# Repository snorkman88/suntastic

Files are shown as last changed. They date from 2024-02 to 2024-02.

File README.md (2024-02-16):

# DRAFT: Suntastic
An ultra low-power management board for meshtastic solar repeater devices.

## Overview

This repository contains the design proposal of a power management board for ultra low power embedded devices. The board features a solar charger circuit with Maximum Power Point Tracking (MPPT) for 5V solar panels, two DC-DC converters, a load switch control with adjustable hysteresis and an external Watchdog Timer.

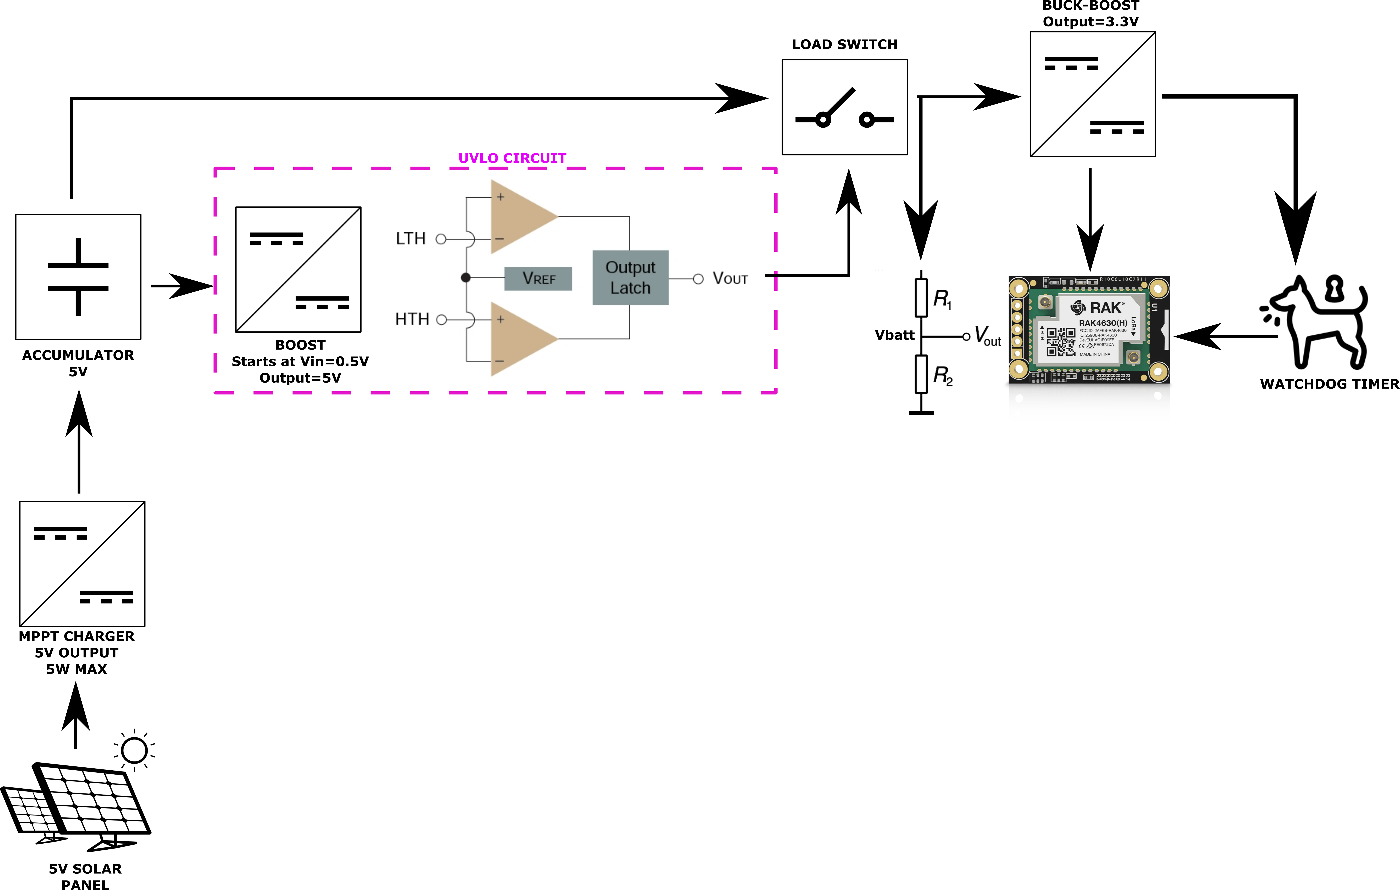
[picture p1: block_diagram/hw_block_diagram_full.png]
Hardware block diagram


## Why did I start this project?

### MPPT is a must
I recently started working with [Meshtastic](https://meshtastic.org/) and decided to deploy solar powered repeaters based on the WisBlock Core module that contains a RAK4631. So far it's been recommended to use this core module with any of the available base boards, however after inspecting [RAK's 19007](https://store.rakwireless.com/products/rak19007-wisblock-base-board-2nd-gen) base board, I noticed that the battery charging stage based on the [TP4054](https://www.laskakit.cz/user/related_files/tp4054.pdf) is not performing any kind of optimization to maximize the power available from the solar input.  

In contrast to linear chargers, MPPT chargers excel in extracting energy from solar panels under conditions such as partial shading, changing light angles, and fluctuating weather conditions. This adaptability is crucial for maximizing energy harvesting in real-world scenarios. By efficiently managing the charging process, MPPT helps prevent overcharging or undercharging of the accumulators in small IoT devices. This contributes to extending the overall lifespan of the battery, reducing the frequency of maintenance or battery replacement, and enhancing the device's reliability.  

### Reduce the current consumption of all the additional electronics
The recommended Wisblock base board RAK19007 contains extra electronics that are not really necessary once the RAK4631 core module has been correctly configured and flashed. This extra electronics however, do imply extra power consumption.  

As it's been empirically proven in [this thread](https://meshtastic.discourse.group/t/running-rak4631-without-the-rak19007/7021/21) once the RAK4631 core is flashed, it only needs a proper 3.3V power source to start working.  
However RAK actually recommends providing two voltage sources to the RAK4631, one that supplies power to the input of internal DC-DC buck converter and another 3.3V for the SX1262 chip. [SEE THIS POST](https://forum.rakwireless.com/t/rak4631-without-baseboard/10177/18)

### Supercapacitors as main energy storage
Another point that motivated the start of this project is the use of supercapacitors instead of conventional LiPo or LiFePo batteries. Whether supercapacitors are better than batteries for IoT devices depends on the specific requirements of the application. Here are some factors to consider:

1. Power Density:
Supercapacitors generally have higher power density than batteries. They can quickly charge and discharge, making them suitable for applications that require rapid bursts of energy. This can be advantageous in IoT devices that need to transmit data or perform periodic tasks quickly.

2. Cycle Life:
Supercapacitors often have a longer cycle life compared to batteries. Compared to batteries, they can withstand a large number of charge-discharge cycles without significant degradation in their structure even when being completely depleted and its output voltage drops down to 0V. This is beneficial for IoT devices that may need to operate for extended periods without maintenance.

3. Lifetime and Maintenance:
Supercapacitors can have a longer overall lifetime than batteries, as they do not suffer from the same degradation issues over time. They also require less maintenance since they do not have the same chemical processes that can lead to wear and tear in batteries.

4. Size and Weight:
Supercapacitors can be more compact and lighter than batteries, which is important for IoT devices with size and weight constraints. This is particularly relevant for small, portable devices or those with limited space.

5. Temperature Sensitivity:
Supercapacitors are known for their resilience to temperature variations, making them suitable for applications in harsh environments. This can be an advantage in IoT devices deployed in diverse environments where temperature fluctuations are common. Supercapacitors have a temperature range of operation og -40°C to 85°C or even higher in some cases.

6. Energy Density:
Batteries typically have higher energy density, meaning they can store more energy per unit of volume or weight. If the IoT device requires long periods of operation without recharging, a battery might be a more suitable choice.

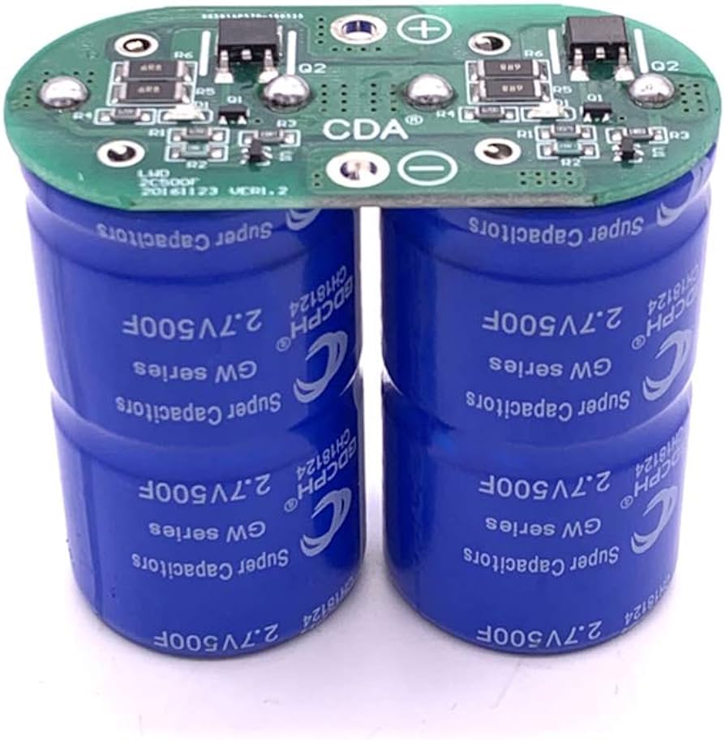
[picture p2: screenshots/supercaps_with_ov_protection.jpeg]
supercaps
  

In summary, the choice between supercapacitors and batteries for powering IoT devices depends on the specific requirements of the application. Supercapacitors may be a better choice for applications that require high power density, quick charge/discharge cycles, and long cycle life, while batteries may be preferable when higher energy density and longer operating periods without recharging are crucial. Each technology has its own strengths and limitations, and the decision should be based on the specific needs and constraints of the IoT deployment.  

### External Watchdog timers are sometimes needed
For IoT devices deployed in remote areas, the incorporation of an external watchdog timer becomes even more critical due to the challenges associated with limited accessibility and maintenance. Remote locations often entail harsh environmental conditions and restricted physical access, making it challenging to address issues promptly. The watchdog timer becomes a crucial asset in such scenarios as it autonomously monitors the device's operational state and intervenes in the case of failures. This capability ensures that even if a device experiences a software glitch or hardware malfunction, it can autonomously reset itself, mitigating potential downtime without requiring manual intervention.  

The reliability and self-correcting nature of an external watchdog timer contribute significantly to the overall resilience of IoT devices in remote deployments, enhancing their ability to function autonomously and maintain consistent operation in challenging and hard-to-reach environments.

## IMPORTANT
IMPORTANT: this board has been specifically thought to handle 5V solar panels and supercapacitors up to a voltage of 5.4V max.

## Table of Contents

- [Solar Charger Circuit](#solar-charger-circuit)
- [DC-DC Converters](#dc-dc-converters)
  - [Boost Converter](#boost-converter)
  - [Buck-Boost Converter](#buck-boost-converter)
- [UVLO - Schmitt Trigger Control](#schmitt-trigger-control)
- [External Watchdog timer](#watchdog-timer)
- [Monitoring of the voltage seen on the accumulator]()

## Solar Charger Circuit

The solar charger circuit is designed to efficiently charge an accumulator using 5V solar panels. It incorporates Maximum Power Point Tracking (MPPT) to optimize the energy harvesting from the solar panels.  

The [SPV1040](https://www.st.com/en/power-management/spv1040.html) device is a low power, low voltage, monolithic step-up converter with an input voltage range from 0.3 V to 5.5 V, capable of maximizing the energy generated by solar cells (or fuel cells), where low input voltage handling capability is extremely important. Thanks to the embedded MPPT algorithm, even under varying environmental conditions (such as irradiation, dirt, temperature) the SPV1040 offers maximum efficiency in terms of power harvested from the cells and transferred to the output. The device employs a voltage regulation loop, which fixes the charging battery voltage via a resistor divider.  



It is possible to set the maximum output current according to charging requirements by a sense resistor .

## DC-DC Converters

### Boost Converter

The first DC-DC converter that is presented is a boost converter responsible for powering the control stage and the input of the internal DC/DC converter present in the nRF52840.  
It is based on a [TPS61202](https://www.sparkfun.com/datasheets/Prototyping/tps61200.pdf) from Texas Instruments and takes variable voltage seen at the accumulator (i.e a supercapacitor) and converts it to a 5V one.  
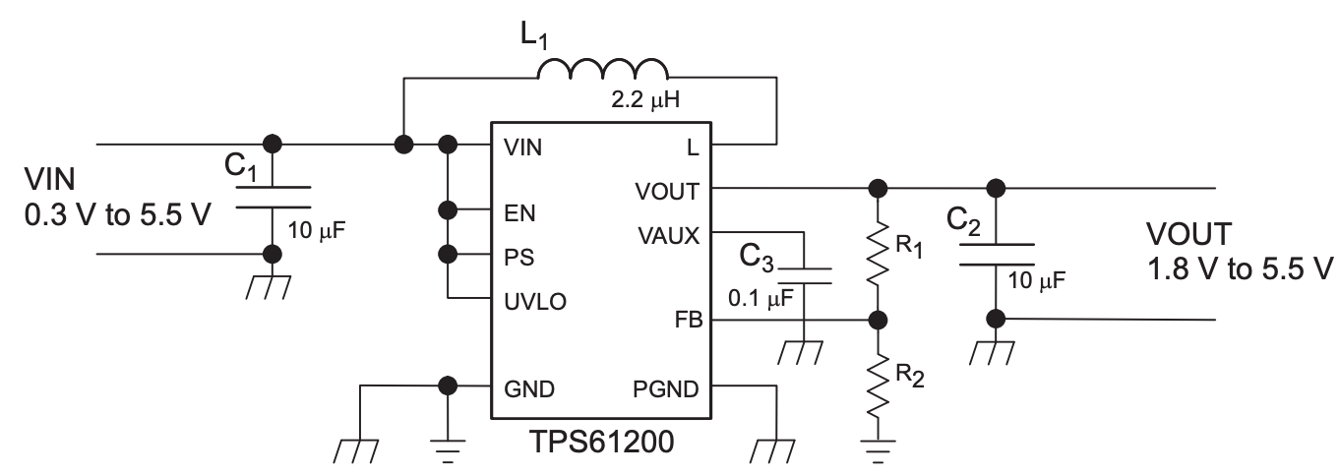
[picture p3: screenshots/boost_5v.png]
boost_5v
  
This boost converter features a very low start-up voltage (0.5V) and Iq=50uA when in operation.  
For the very first version of this board, in order to save schematic and PCB design time, it would be ideal to use a ready-to-use board like the Pololu [U1V10F5](https://thepihut.com/products/pololu-5v-step-up-voltage-regulator-u1v10f5).  

For more info about this module visit [Pololu Site](https://www.pololu.com/product/2564)

### Buck-Boost Converter or LDO for obtaining 3.3V

The second voltage regulator is in charge of supplying power to the 3.3 V bus to which the SX1262 chip (present in the WisBlock RAK4631) and watchdog timer are connected.  
This regulator should only start operating after the load switch controlled by the UVLO is closed.  
It is very important to remark that clean power supplies are essential for RF transceivers to maintain optimal performance. RF signals are sensitive to electrical noise, and any disruptions in the power supply can lead to signal degradation.  

In the case a buck-boost converter (like the TPS63020) is adopted, then it could either take as an input the variable voltage from the supercapacitor or the 5V constant output coming out of the TPS61202. This approach however, necessitates more filtering of the output voltage.  

Using LDOs on the other hand, requires an input votlage higher than the one desired at the output (in this case 3.3V). Ergo, connecting its input directly to the supercapacitor is not an acceptable approach.  
Although taking 5V coming from the TPS61202 as input voltage might bring some input ripple, the PSRR of an LDO contributes to suppress it at the output.  
In the case the output of the LDO still shows some ringing at high frequencies (usually as peaks on the waveform), ferrite beads should be placed to filter the desired frequencies.  

For more detailed info about this visit this [Application Note from Analog Device - AN101](https://www.analog.com/media/en/technical-documentation/application-notes/an101f.pdf)  

or watch this video  

[![Video]()](https://www.youtube.com/watch?v=WxhjLIu-vPg&ab_channel=LinearTechnology)

### Why are there two DC-DC converters?
It is desirable that the UVLO control circuit starts operating as early as possible if there is enough input power (around Vin=0.7V) and BEFORE any other electronic device. The opposite behaviour is also desired. In other words, when the input voltage coming from the accumulator decreases, the UVLO should be last part that is turned off.

Since it's expected that the control stage consumes only a few microamps when operating, the output voltage of 5V should remain steady while the accumulator (i.e: supercapacitor) continues to charge. Once the voltage seen accross the terminals of the accumulator reaches the lock-in voltage, the second converter, external watchdog timer and microcontroller will be energised.

## UVLO - Schmitt Trigger Control

The project includes an UVLO circuit with with adjustable hysteresis that enables or disables a load switch. The load connected to the switch will be the main [Buck-Boost Converter](#buck-boost-converter) that feeds power the RAK431 or another microcontroller.  

Since the supercapacitor bank I have at the moment (250F x 5.4V) already comes with an extra PCB to protect them against overvoltages higher than 5V, and for [this simulation only](https://www.falstad.com/circuit/circuitjs.html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), a value of 3V was chosen for the upper limit and 1V for the lower one.  

Since it's the intention to make the supercapacitor charge up to a voltage value close to the maximum, the final version will have a lock-in voltage closer to 5V or 5.4V if I get a bank without the overvoltage protection. The lower limit of the hysterisis window will be kept at 1V.  
In order to avoid flickering of the output when the supercap voltage reaches the lock-in and -out values, an SR latch based on NOR gates will either SET (and keep it HIGH even if the input flickers) when the lock-in voltage is reached; and RESET its output when reaching the lock-out value.  

The circuit consists of two [TLV3691](https://www.ti.com/lit/ds/symlink/tlv3691.pdf?ts=1706791844150&ref_url=https%253A%252F%252Fwww.google.com%252F) nano-power comparators powered by the 5V bus.  

For the voltage references, it's yet to be defined if specific high-precision voltage references like [REF35](https://www.ti.com/lit/ds/symlink/ref35.pdf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) will be used or simply get those reference values from a voltage divider. **Current consumption reduction is PRIORITY.**

For the latching of the output, low power [SN74AUP2G02](https://www.ti.com/lit/ds/symlink/sn74aup2g02.pdf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) NOR gates will be used. These gates will also be powered by the 5V bus.

The load switch will be a [TPS22917](https://www.ti.com/lit/ds/symlink/tps22917.pdf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).

In summary this circuit makes sure the embedded device stays de-energised until the supercapacitor is fully charged.

## Watchdog timer  

If for any unforeseen reason, the voltage supplied to the core module drops low enough that the device shuts down or to a level that causes a brown-out, it may not be able to resume its normal operation by itself without external intervention (manually or by automation) that either removes and reconnects the voltage supply or issues a reset.  

An external watchdog timer will issue a reset in case of a software bug/glitch or brownout will be a [TPL5010](https://www.ti.com/lit/ds/symlink/tpl5010.pdf?ts=1706954677109&ref_url=https%253A%252F%252Fwww.google.com%252F) from Texas Instrument.  

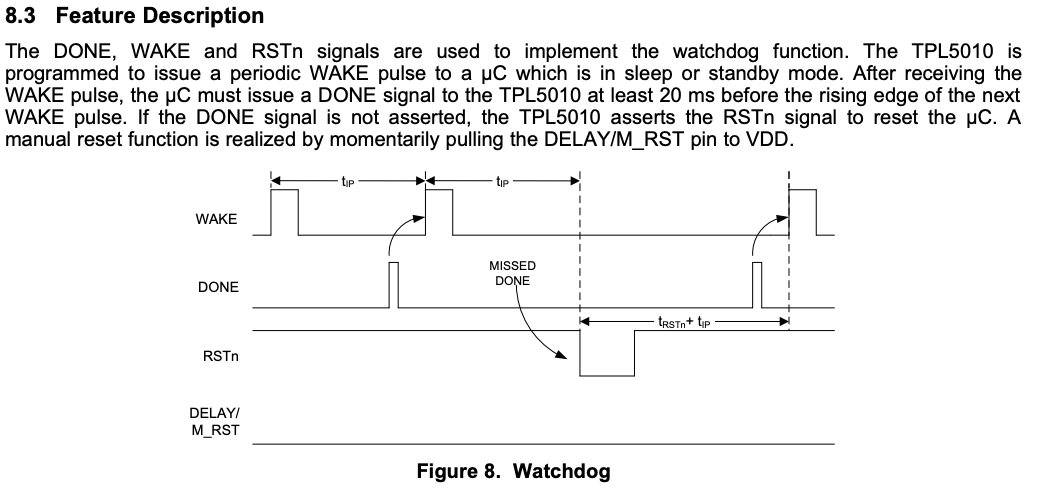
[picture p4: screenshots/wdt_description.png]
description_wdt
  

The DONE signal resets the counter of the watchdog only. If the DONE signal is received when the WAKE is still high, the WAKE will go low as soon as the DONE is recognized.
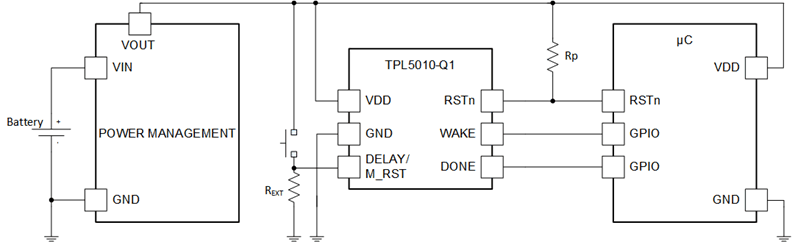
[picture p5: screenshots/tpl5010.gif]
external_wdt
  

For this feature to be fully functional, two GPIO pins and **CHANGES IN THE CORE MODULE FIRMWARE ARE NEEDED** to monitor the WAKE signal and generate a DONE pulse to reset the counter of the  WDT.  
Images taken from the datasheet.  

## Monitoring the current voltage on the supercapacitor
Also mentioned in [this thread](https://meshtastic.discourse.group/t/running-rak4631-without-the-rak19007/7021/21). A voltage divider must be connected to Pin40 (P0.05/AIN3) of the RAK4631.  
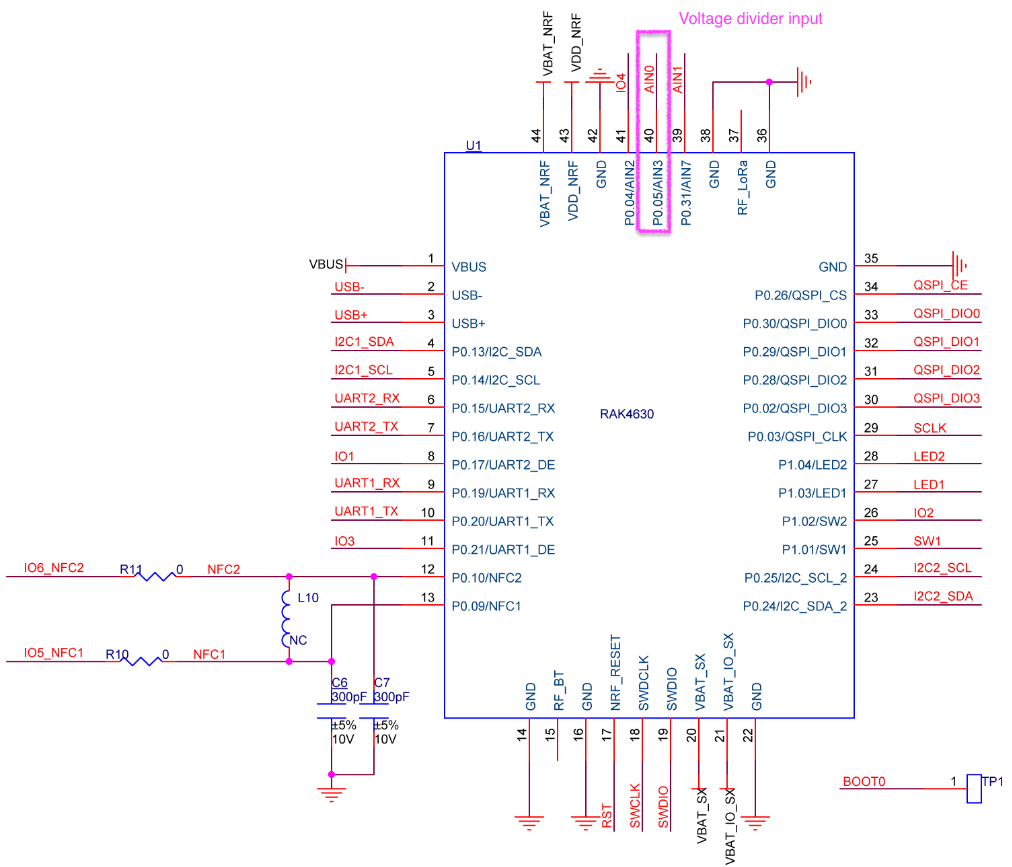
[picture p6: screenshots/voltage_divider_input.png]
voltage_divider
  

**CHANGES IN THE CORE MODULE FIRMWARE ARE NEEDED TOO** in order to properly reflect the current voltage value on the supercapacitor based on the resistors ratio from the voltage divider.

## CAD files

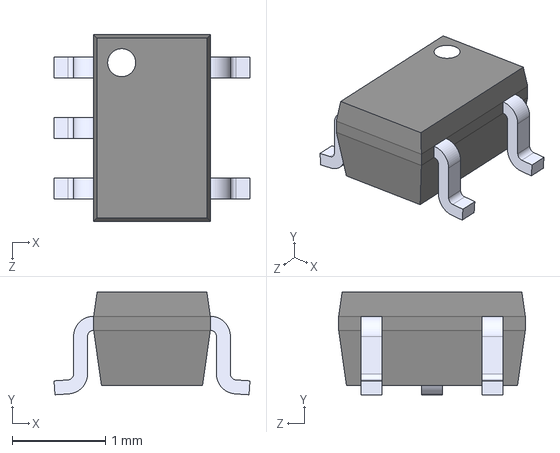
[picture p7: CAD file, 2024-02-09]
pcb/suntastic/suntastic_3D_models/TLV3691IDCKR.step
2.10 x 1.10 x 2.00 mm

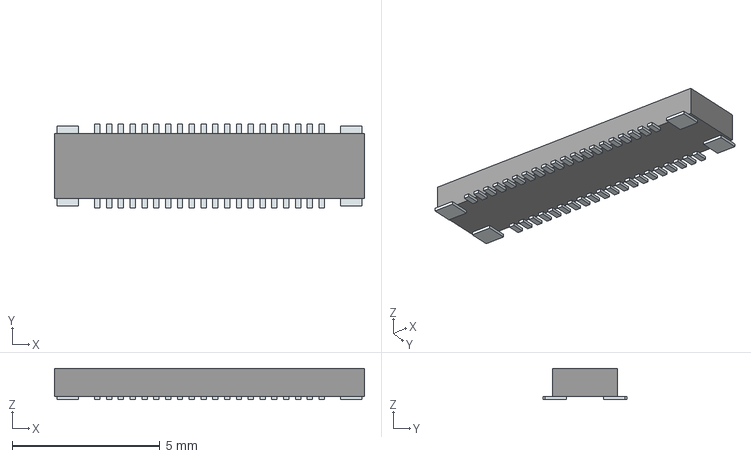
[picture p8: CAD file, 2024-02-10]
pcb/suntastic/suntastic_3D_models/FBB04004-F40S1003K6M.stp
10.5 x 2.85 x 1.05 mm
Pins

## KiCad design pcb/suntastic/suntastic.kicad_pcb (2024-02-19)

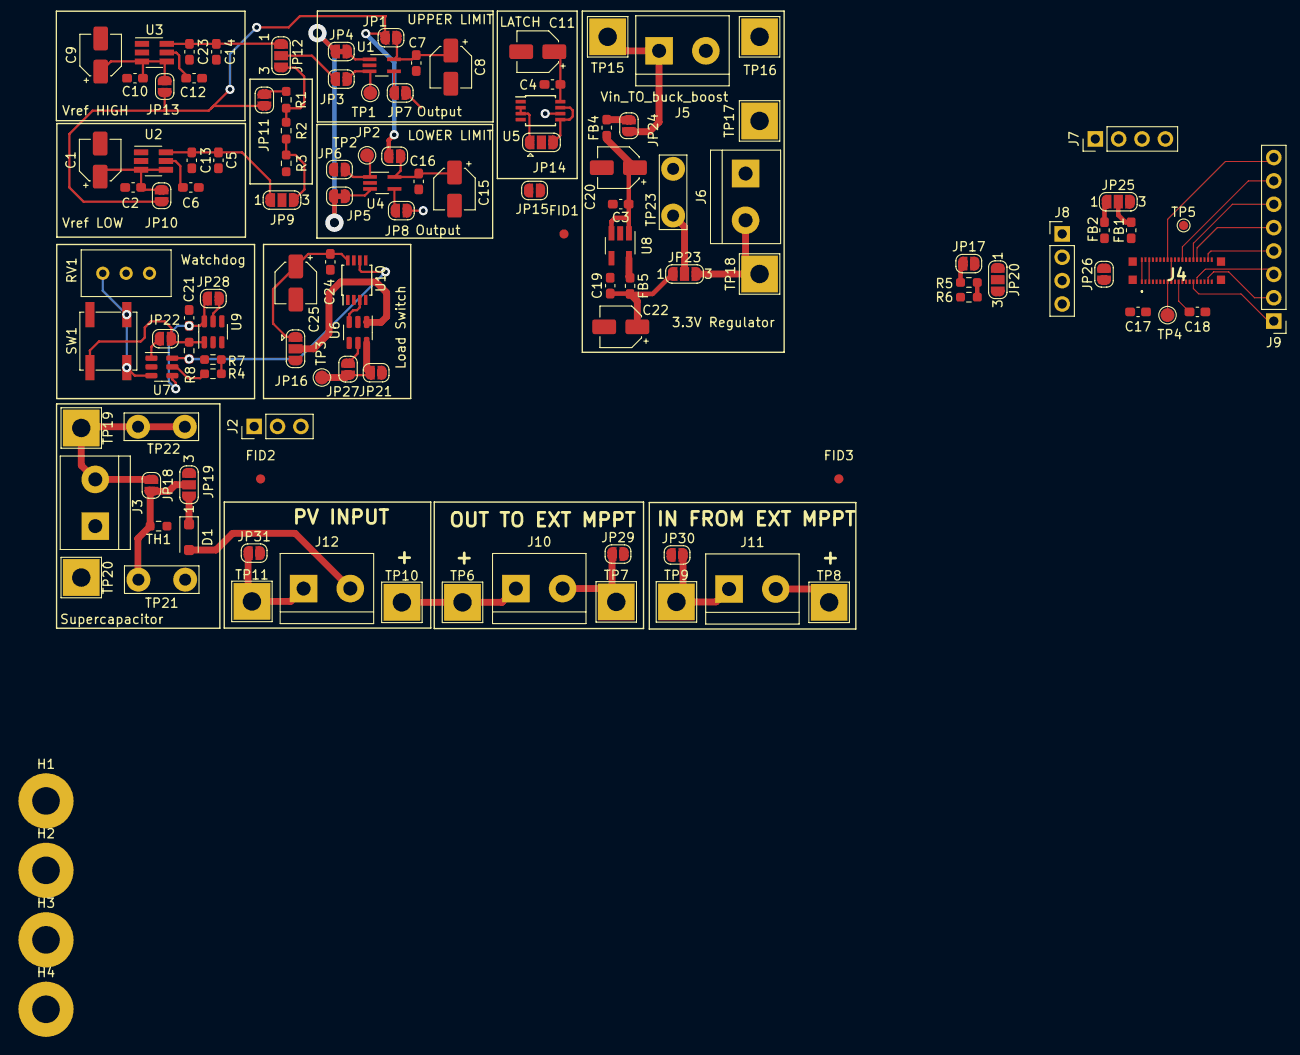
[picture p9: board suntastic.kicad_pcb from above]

Board: 2 copper layers, 120 parts (0 on the bottom side), 78 nets.

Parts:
C1, C9: 2.2uF; CP_Elec_4x5.4
C2, C4, C5, C6, C7, C10, C12, C14, C16, C17, C18, C24: 0.1uF; C_0603_1608Metric_Pad1.08x0.95mm_HandSolder
C3, C13, C19, C21, C23: 1uF; C_0603_1608Metric_Pad1.08x0.95mm_HandSolder
C8, C15: 4.7uF; CP_Elec_4x5.4
C11, C25: 1uF; CP_Elec_4x4.5
C20, C22: 10u; CP_Elec_4x4.5
D1: PMEG10020ELR; D_SOD-123F
FB1, FB2, FB4, FB5: FerriteBead; L_0603_1608Metric_Pad1.05x0.95mm_HandSolder
FID1, FID2, FID3: Fiducial; Fiducial_1mm_Mask3mm
H1, H2, H3, H4: MountingHole; MountingHole_3mm_Pad
J2: Pololu U1V10F5; PinHeader_1x03_P2.54mm_Vertical
J3: Supercap IN; TerminalBlock_bornier-2_P5.08mm
J4: FBB04004-F40S1003K6M; FBB04004F40S1003K6M
J5: Vin_TO_buck_boost; TerminalBlock_bornier-2_P5.08mm
J6: Vout_FROM_buck_boost; TerminalBlock_bornier-2_P5.08mm
J7, J8: Conn_01x04_Pin; PinHeader_1x04_P2.54mm_Vertical
J9: Conn_01x08_Pin; PinHeader_1x08_P2.54mm_Vertical
J10: OUT TO EXT MPPT; TerminalBlock_bornier-2_P5.08mm
J11: INPUT FROM EXT MPPT; TerminalBlock_bornier-2_P5.08mm
J12: PV IN; TerminalBlock_bornier-2_P5.08mm
JP1, JP2, JP3, JP6, JP7, JP8, JP10, JP11, JP13, JP15, JP17, JP21, JP22, JP24, JP26, JP27, JP28: SolderJumper_2_Open; SolderJumper-2_P1.3mm_Open_RoundedPad1.0x1.5mm
JP4, JP5: SolderJumper_2_Bridged; SolderJumper-2_P1.3mm_Bridged_RoundedPad1.0x1.5mm
JP9, JP12, JP19, JP20, JP23, JP25: SolderJumper_3_Open; SolderJumper-3_P1.3mm_Open_RoundedPad1.0x1.5mm_NumberLabels
JP14, JP16: SolderJumper_3_Open; SolderJumper-3_P1.3mm_Open_RoundedPad1.0x1.5mm
JP18, JP29, JP30, JP31: Jumper_2_Open; SolderJumper-2_P1.3mm_Open_RoundedPad1.0x1.5mm
R1, R7: 3.3M; R_0603_1608Metric_Pad0.98x0.95mm_HandSolder
R2, R6: 9.3M; R_0603_1608Metric_Pad0.98x0.95mm_HandSolder
R3: 3.9M; R_0603_1608Metric_Pad0.98x0.95mm_HandSolder
R4: 1.8M; R_0603_1608Metric_Pad0.98x0.95mm_HandSolder
R5: 5.6M; R_0603_1608Metric_Pad0.98x0.95mm_HandSolder
R8: R; R_0603_1608Metric_Pad0.98x0.95mm_HandSolder
RV1: 120k; Potentiometer_Bourns_3296W_Vertical
SW1: EVP-BF6C1A000; SW_SPST_EVPBF
TH1: Thermistor_PTC; R_0603_1608Metric_Pad0.98x0.95mm_HandSolder
TP1: Vref_high; TestPoint_Pad_D1.5mm
TP2: Vref_low; TestPoint_Pad_D1.5mm
TP3: Vout_switch; TestPoint_Pad_D1.5mm
TP4: LED2; TestPoint_Pad_D1.5mm
TP5: LED1; TestPoint_Pad_D1.0mm
TP6: PV_TO_MPPT; TestPoint_THTPad_4.0x4.0mm_Drill2.0mm
TP7: GND_TO_MPPT; TestPoint_THTPad_4.0x4.0mm_Drill2.0mm
TP8: OUT_FROM_MPPT; TestPoint_THTPad_4.0x4.0mm_Drill2.0mm
TP9: GND_FROM_MPPT; TestPoint_THTPad_4.0x4.0mm_Drill2.0mm
TP10: PV_VIN; TestPoint_THTPad_4.0x4.0mm_Drill2.0mm
TP11: PV_GND; TestPoint_THTPad_4.0x4.0mm_Drill2.0mm
TP15, TP16, TP17, TP18: TestPoint; TestPoint_THTPad_4.0x4.0mm_Drill2.0mm
TP19: SC_VIN; TestPoint_THTPad_4.0x4.0mm_Drill2.0mm
TP20: SC_GND; TestPoint_THTPad_4.0x4.0mm_Drill2.0mm
TP21, TP22: TestPoint; TestPoint_Bridge_Pitch5.08mm_Drill1.3mm
TP23: 3.3V; TestPoint_Bridge_Pitch5.08mm_Drill1.3mm
U1, U4: TLV3691IDCKR; SOT-353_SC-70-5_Handsoldering
U2: REF35102QDBVR; SOT-23-6_Handsoldering
U3: REF35409QDBVR; SOT-23-6_Handsoldering
U5: TC7WH02FU_LJCT; TSSOP-8_3x3mm_P0.65mm
U6, U9: TPS22917DBV; SOT-23-6
U7: TPL5010; SOT-23-6
U8: XC6220B331MR; SOT-23-5_HandSoldering
U10: TC7WH08FK_LJCT; TSSOP-8_3x3mm_P0.65mm

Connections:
3.3V: FB2.1, JP23.2 (C), JP25.1 (A), TP23.1
/Sheetname: UVLO with latched output/NOR_1_OUT: JP14.3 (B), U5.5, U5.7
/Sheetname: UVLO with latched output/NOR_2_OUT: JP14.1 (A), U5.2, U5.3
/Sheetname: UVLO with latched output/RESET: JP7.2 (B), U5.1
/Sheetname: UVLO with latched output/SET: JP8.2 (B), U5.6
/WisBlock Core Module - RAK4631/3V3: FB2.2, J4.5, J4.6, JP26.2 (B)
/WisBlock Core Module - RAK4631/AIN0: C18.1, J4.21, JP20.3 (B)
/WisBlock Core Module - RAK4631/AIN1: J4.22, JP20.1 (A)
/WisBlock Core Module - RAK4631/BOOT0: J4.23, J7.1
/WisBlock Core Module - RAK4631/IO1: J4.29, J9.1
/WisBlock Core Module - RAK4631/IO2: J4.30, J9.6
/WisBlock Core Module - RAK4631/IO3: J4.31, J9.3
/WisBlock Core Module - RAK4631/IO4: J4.32, J9.5
/WisBlock Core Module - RAK4631/IO5: J4.37, J9.2
/WisBlock Core Module - RAK4631/IO6: J4.38, J9.4
/WisBlock Core Module - RAK4631/IO7: J4.24, J9.7
/WisBlock Core Module - RAK4631/IO8: J4.16, J9.8
/WisBlock Core Module - RAK4631/RXD0: J4.12, J8.4
/WisBlock Core Module - RAK4631/RXD1: J4.34, J7.4
/WisBlock Core Module - RAK4631/TXD0: J4.11, J8.3
/WisBlock Core Module - RAK4631/TXD1: J4.33, J7.3
/WisBlock Core Module - RAK4631/VBAT_nRF: FB1.2, J4.1, J4.2
/WisBlock Core Module - RAK4631/VDD_nRF: J4.17, J4.18, JP26.1 (A)
/WisBlock Core Module - RAK4631/Vsupercap: JP20.2 (C), R5.2, R6.1
GND: C1.2, C2.2, C3.2, C4.2, C5.2, C6.2, C7.2, C8.2, C9.2, C10.2, C11.2, C12.2, C13.2, C14.2, C15.2, C16.2, C17.2, C18.2, C19.2, C20.2, C21.2, C22.2, C23.2, C24.2, C25.2, J2.2, J3.1, J4.3, J4.4, J4.39, J4.40, J4.MP1, J4.MP2, J4.MP3, J4.MP4, J5.2, J6.1, J7.2, J8.2, JP29.2 (B), JP30.2 (B), JP31.2 (B), R3.2, R6.2, R7.2, RV1.2, RV1.3, TP16.1, TP17.1, TP20.1, U1.2 (GND), U2.1 (GND), U2.2 (GND), U3.1 (GND), U3.2 (GND), U4.2 (GND), U5.4, U6.2 (GND), U7.2 (GND), U8.2 (GND), U9.2 (GND), U10.1 (1A), U10.2 (1B), U10.4 (GND)
GPIO_WAKE: R4.2, R7.1
LOAD_SWITCH_CTRL: JP14.2 (C), JP15.1 (A)
MPPT_OUT: J11.2, JP19.3 (B), TP8.1
unnamed: D1.1 (K), JP19.1 (A)
unnamed: J3.2, JP18.1 (A), TP19.1, TP22.1
unnamed: J4.14, TP5.1
unnamed: J4.15, TP4.1
unnamed: J6.2, JP23.3 (B), TP18.1
unnamed: J10.2, JP29.1 (A), TP7.1
unnamed: J11.1, JP30.1 (A), TP9.1
unnamed: J12.1, JP31.1 (A), TP11.1
unnamed: C7.1, C8.1, JP1.1 (A), U1.5 (VCC)
unnamed: C15.1, C16.1, JP2.1 (A), U4.5 (VCC)
unnamed: JP3.2 (B), TP1.1, U1.3 (IN-)
unnamed: JP4.2 (B), U1.1 (IN+)
unnamed: JP5.2 (B), U4.3 (IN-)
unnamed: JP6.2 (B), TP2.1, U4.1 (IN+)
unnamed: JP7.1 (A), U1.4 (OUT)
unnamed: JP8.1 (A), U4.4 (OUT)
unnamed: C5.1, C13.1, JP9.1 (A), U2.6 (VREF)
unnamed: JP9.3 (B), R2.2, R3.1
unnamed: C1.1, C2.1, JP10.2 (B), U2.3 (EN), U2.4 (VIN)
unnamed: JP11.2 (B), R1.1
unnamed: C14.1, C23.1, JP12.1 (A), U3.6 (VREF)
unnamed: JP12.3 (B), R1.2, R2.1
unnamed: C9.1, C10.1, JP13.2 (B), U3.3 (EN), U3.4 (VIN)
unnamed: JP15.2 (B), U10.5 (2A)
unnamed: JP16.2 (C), U6.1 (VIN)
unnamed: JP17.2 (B), R5.1
unnamed: JP18.2 (B), JP19.2 (C), TH1.2, TP21.1
unnamed: JP21.1 (A), JP27.2 (B), TP3.1, U6.6 (VOUT)
unnamed: JP22.2 (B), U7.1 (VDD)
unnamed: C19.1, C22.1, FB5.2, JP23.1 (A)
unnamed: FB4.1, JP24.2 (B)
unnamed: FB1.1, JP25.2 (C)
unnamed: JP27.1 (A), U6.5 (QOD)
unnamed: C21.1, JP28.1 (A), U7.4 (DONE), U9.6 (VOUT)
unnamed: JP28.2 (B), U9.5 (QOD)
unnamed: C6.1, U2.5 (NR)
unnamed: C12.1, U3.5 (NR)
unnamed: RV1.1, SW1.1, U7.3 (DELAY/M_RST)
unnamed: R4.1, U7.5 (WAKE)
unnamed: C3.1, C20.1, FB4.2, U8.1 (VIN), U8.3 (CE)
unnamed: FB5.1, U8.5 (VOUT)
unnamed: U6.3 (ON), U10.3 (OUT_2)
PV_+: D1.2 (A), J10.1, J12.2, TP6.1, TP10.1
RST_SIGNAL: R8.2, U7.6 (~RST), U10.6 (2B)
V_boost_uvlo: C4.1, C11.1, C24.1, C25.1, J2.3, JP1.2 (B), JP2.2 (B), JP10.1 (A), JP11.1 (A), JP13.1 (A), JP16.1 (A), JP22.1 (A), JP25.3 (B), R8.1, SW1.2, U5.8, U9.1 (VIN), U10.8 (VDD)
V_supercap: J2.1, JP4.1 (A), JP5.1 (A), JP16.3 (B), JP17.1 (A), TH1.1
Vin_buck_boost: J5.1, JP21.2 (B), JP24.1 (A), TP15.1
Vref_high: JP3.1 (A), JP12.2 (C)
Vref_low: JP6.1 (A), JP9.2 (C)
nRF_RESET: C17.1, J4.13

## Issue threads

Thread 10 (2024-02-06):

Add a 3 way jumper to the input of the load switch

snorkman88, 2024-02-06:
In order to be able to choose between the regulated 3.3V from the output of the buck integrated in the BQ25570 or the unregulated voltage from the super capacitor add a 3 way jumper at the input of the load switch.

Closed 2024-02-07.

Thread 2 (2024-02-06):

Add MPPT charger based on BQ25570 to charge the supercaps up to a voltage of 5 or 5.4

snorkman88, 2024-02-06:
This part is crucial and should involve more than person.
As a reference design [Michael Aicher's design](https://www.mikes-garage.info/?page_id=31) does exactly what it's desired here. He used supercapacitors as his main energy storage and replaced the resistors that set the output voltage to a value close to 5.4V.

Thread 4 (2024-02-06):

Add solder jumper on PCB to disconnect MPPT charger output from the super capacitor and add Diode for direct PV input

snorkman88, 2024-02-06:
If a person decides he wants to charge the supercap just by hooking up a PV directly, that is to say without using any electronic that performs MPPT, he should be allowed to do so.

In order to achieve this, the output of the MPPT charger should have a solder jumper that disconnect its output from the super capacitor.

Additionally, when connecting a PV directly a diode should be placed in order to avoid the discharge of the supercap.

snorkman88, 2024-02-10:
@MoNoMXT I already added a three 3 way solder jumper in the **Supercapacitor input sheet**. Check the image below.
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

snorkman88, 2024-02-10:
@MoNoMXT see global label names

Closed 2024-02-10.

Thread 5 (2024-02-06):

UVLO: Add two sources of voltage references

snorkman88, 2024-02-06:
For the very first version two optional approaches will be added in order to evaluate their performance

1. Add 2 voltage references (Vil=1.024 and Vih=3.3) based on REF35
2. Get those reference voltages using a voltage divider based on megaohms resistors
  - Allow `sandwiching` of 2 resistors

snorkman88, 2024-02-09:
Done! We can now choose between two type of voltage  references: either based on REF35xxx or resistor array.

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

Closed 2024-02-09.

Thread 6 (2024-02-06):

UVLO: add PCB solder jumper for disconnecting Vbat input

snorkman88, 2024-02-06:
To make the debugging process easier, add a jumper and a test point to disconnect Vbat.

snorkman88, 2024-02-09:
Done!

Closed 2024-02-09.

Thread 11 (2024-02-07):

Add boost converter for the UVLO circuit

snorkman88, 2024-02-07:
It is _MANDATORY_ for this converter to have a starup voltage of AT LEAST 0.7V or less.

The initial draft suggested to use the [TPS610981](https://www.ti.com/lit/ds/symlink/tps610985.pdf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).

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
However, the max ouptut voltage for the TPS610981 is 4.3V. Ideally 5V would be desired.

The Pololu U1V10F5 module the other hand, seems like the perfect fit for the very first prototype since its a ready-to-use board with only 3 pins required for the connection.
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
This board features a TPS61202  and accepts input voltages as low as 0.5V to start working

snorkman88, 2024-02-10:
Decided to add a connector for Pololu's U1V10F5

Closed 2024-02-10.

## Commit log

2024-02-08 Update boost circuit
2024-02-09 Update boost circuit for UVLO
2024-02-09 Add UVLO and latch schematics
    [TLV3691IDCKR.step, boost_for_uvlo.kicad_sch, load_switch_output.kicad_sch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]
2024-02-09 Rename sheet
    [boost_for_uvlo.kicad_sch, load_switch_output.kicad_sch, suntastic.kicad_sch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]
2024-02-10 Add load switch and RAK connector
    [FBB04004-F40S1003K6M.stp, boost_for_uvlo.kicad_sch, load_switch_output.kicad_sch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]
2024-02-10 Add more doccstrings
    [boost_for_uvlo.kicad_sch, buck_boost_load.kicad_sch, load_switch_output.kicad_sch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]
2024-02-14 add wdt
    [boost_for_uvlo.kicad_sch, load_switch_output.kicad_sch, suntastic.kicad_sch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]
2024-02-14 Add two alternatives to obtain 3.3V for the SX chip
    [boost_for_uvlo.kicad_sch, buck_boost_load.kicad_sch, load_switch_output.kicad_sch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]
2024-02-16 Update footprints
    [buck_boost_load.kicad_sch, load_switch_output.kicad_sch, supercapacitor_input.kicad_sch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]
2024-02-17 Update more footprints and start with PCB
    [buck_boost_load.kicad_sch, load_switch_output.kicad_sch, suntastic.kicad_pcb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]
2024-02-19 Rework watchdog
    [boost_for_uvlo.kicad_sch, load_switch_output.kicad_sch, suntastic.kicad_pcb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]
2024-02-19 Add screw terminals for external MPPT module and PV input
    [load_switch_output.kicad_sch, mppt_charger.kicad_sch, solar_panel_input.kicad_sch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]
